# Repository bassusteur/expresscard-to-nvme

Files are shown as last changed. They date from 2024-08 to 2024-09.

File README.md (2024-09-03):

# Expresscard to NVMe  
This ExpressCard to NVME adapter is an attempt to revive the Thinkmods project by making the design open source and following the original as closely as possible.  

top
bottom

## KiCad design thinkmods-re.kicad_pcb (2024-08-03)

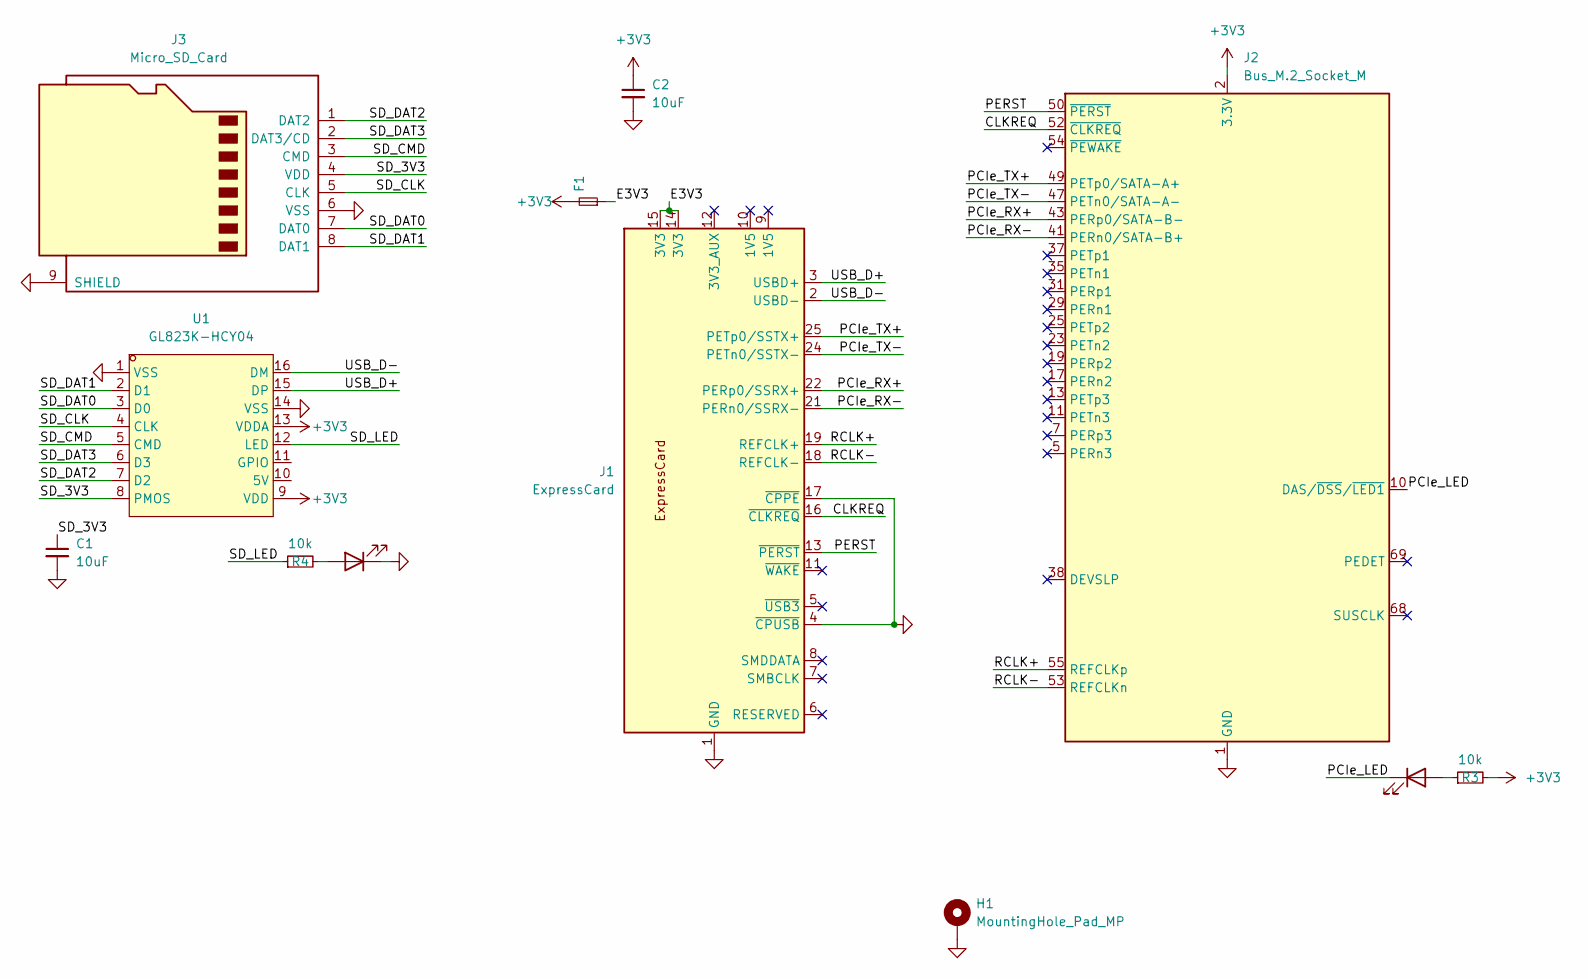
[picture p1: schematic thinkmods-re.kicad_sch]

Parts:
C1, C2: 10uF; C_0603_1608Metric
D1, D2: LED; LED_0603_1608Metric
F1: Fuse_Small; Fuse_0805_2012Metric
H1: MountingHole_Pad_MP; MountingHole_3.2mm_M3_Pad_small
J1: ExpressCard; ExpressCard_Plug
J2: Bus_M.2_Socket_M; CONN-SMD_APCI0159-P001A
J3: Micro_SD_Card; TF-SMD_TF-123-ARP9H15
R3, R4: 10k; R_0402_1005Metric
U1: GL823K-HCY04; SSOP-16_3.9x4.9mm_P0.635mm; LCSC Part C284879

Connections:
+3V3: C2.1, F1.2, J2.2 (3.3V), J2.4 (3.3V), J2.12 (3.3V), J2.14 (3.3V), J2.16 (3.3V), J2.18 (3.3V), J2.70 (3.3V), J2.72 (3.3V), J2.74 (3.3V), R3.2, U1.9 (VDD), U1.13 (VDDA)
/CLKREQ: J1.16 (~CLKREQ), J2.52 (~CLKREQ)
/E3V3: F1.1, J1.14 (3V3), J1.15 (3V3)
/PCIe_LED: D2.1 (K), J2.10 (DAS/~DSS/~LED1)
/PCIe_RX+: J1.22 (PERp0/SSRX+), J2.43 (PERp0/SATA-B-)
/PCIe_RX-: J1.21 (PERn0/SSRX-), J2.41 (PERn0/SATA-B+)
/PCIe_TX+: J1.25 (PETp0/SSTX+), J2.49 (PETp0/SATA-A+)
/PCIe_TX-: J1.24 (PETn0/SSTX-), J2.47 (PETn0/SATA-A-)
/PERST: J1.13 (~PERST), J2.50 (~PERST)
/RCLK+: J1.19 (REFCLK+), J2.55 (REFCLKp)
/RCLK-: J1.18 (REFCLK-), J2.53 (REFCLKn)
/SD_3V3: C1.1, J3.4 (VDD), U1.8 (PMOS)
/SD_CLK: J3.5 (CLK), U1.4 (CLK)
/SD_CMD: J3.3 (CMD), U1.5 (CMD)
/SD_DAT0: J3.7 (DAT0), U1.3 (D0)
/SD_DAT1: J3.8 (DAT1), U1.2 (D1)
/SD_DAT2: J3.1 (DAT2), U1.7 (D2)
/SD_DAT3: J3.2 (DAT3/CD), U1.6 (D3)
/SD_LED: R4.1, U1.12 (LED)
/USB_D+: J1.3 (USBD+), U1.15 (DP)
/USB_D-: J1.2 (USBD-), U1.16 (DM)
GND: C1.2, C2.2, D1.1 (K), H1.MP, J1.1 (GND), J1.4 (~CPUSB), J1.17 (~CPPE), J1.20 (GND), J1.23 (GND), J1.26 (GND), J2.1 (GND), J2.3 (GND), J2.9 (GND), J2.15 (GND), J2.21 (GND), J2.27 (GND), J2.33 (GND), J2.39 (GND), J2.45 (GND), J2.51 (GND), J2.57 (GND), J2.71 (GND), J2.73 (GND), J2.75 (GND), J3.6 (VSS), J3.9 (SHIELD), U1.1 (VSS), U1.14 (VSS)
unnamed: D1.2 (A), R4.2
unnamed: D2.2 (A), R3.1

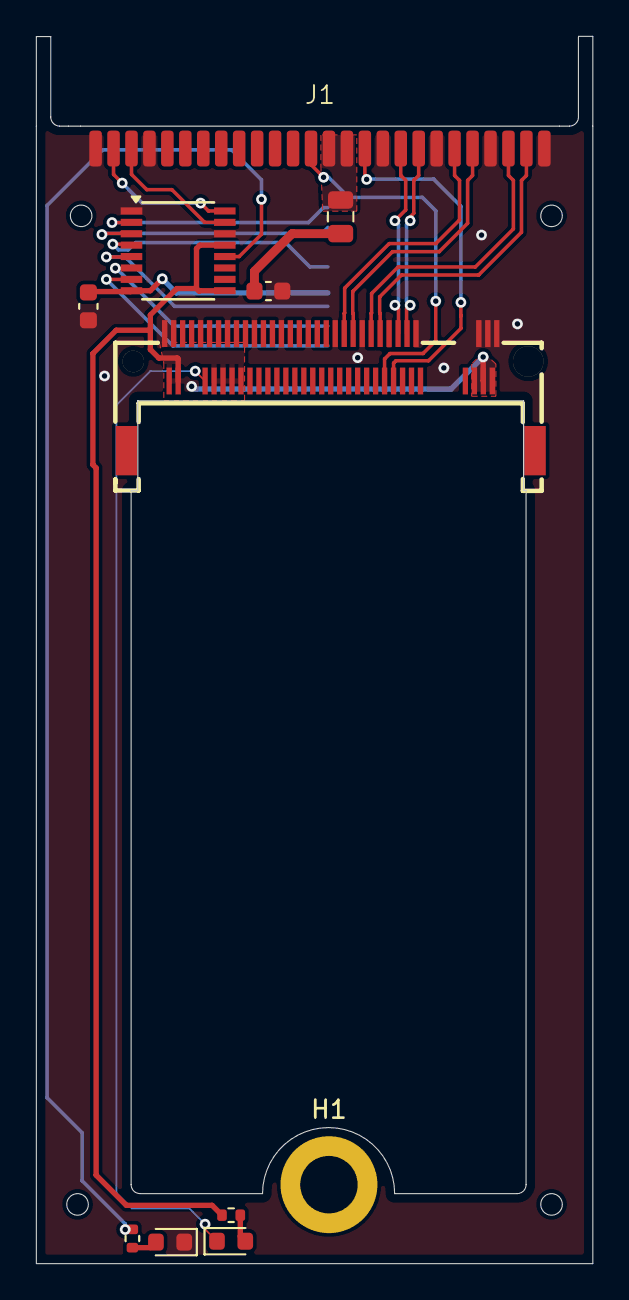
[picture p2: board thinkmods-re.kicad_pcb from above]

Board: 2 copper layers, 31.0 x 68.4 mm, 12 parts (1 on the bottom side), 24 nets.
